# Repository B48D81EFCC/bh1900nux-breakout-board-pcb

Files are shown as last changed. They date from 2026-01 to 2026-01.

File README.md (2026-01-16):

# BH1900NUX Breakout Board PCB
*KiCad project files for a breakout board using the Rohm Semiconductor BH1900NUX temperature sensor.*
## Miniature Temperature Sensor

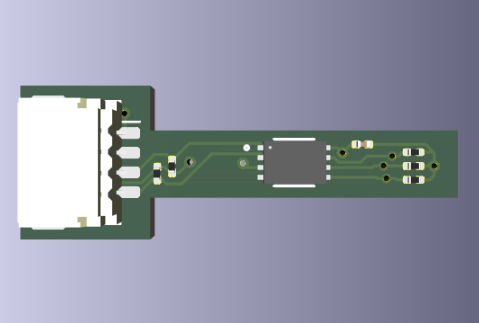
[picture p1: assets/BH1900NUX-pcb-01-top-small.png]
Miniature Temperature Sensor


## Overview
The breakout board simplifies the integration of the **BH1900NUX temperature sensor** into your projects.  
The main goal of this PCB is to have a very compact design that ultimately fits into a stainless steel sleeve with a diameter of around 5mm.

### Features
- **Compact design** of less than 18mm² (0,028 square inch). 
- Connector compatible with many I²C ecosystems
-  **A1 pin** Supported (solder jumper on the back)
- **A2 pin** Supported (solder jumper on the back)
- **A3 pin** Supported (solder jumper on the back)
- **ALERT pin** NOT supported (Pin is not exposed on the PCB)

### JST SH connector pinout

| Pin # | Function |
|---|---|
| 1 | GND |
| 2 | 3.3V |
| 3 | SDA |
| 4 | SCL |

The pinout layout is widely used across different vendors of breakout boards with JST SH connector, allowing to use multiple different sensors on one bus more easily. Although the pin layout is (often) the same, each vendor uses their own brand names (e.g: Qwiic/STEMMA, μŠup, easyC)

> [!CAUTION]
> The design is not 5V compliant and 5V will destroy the sensor.  
> **Use 3.3V only.** 

---
# 3D Render images

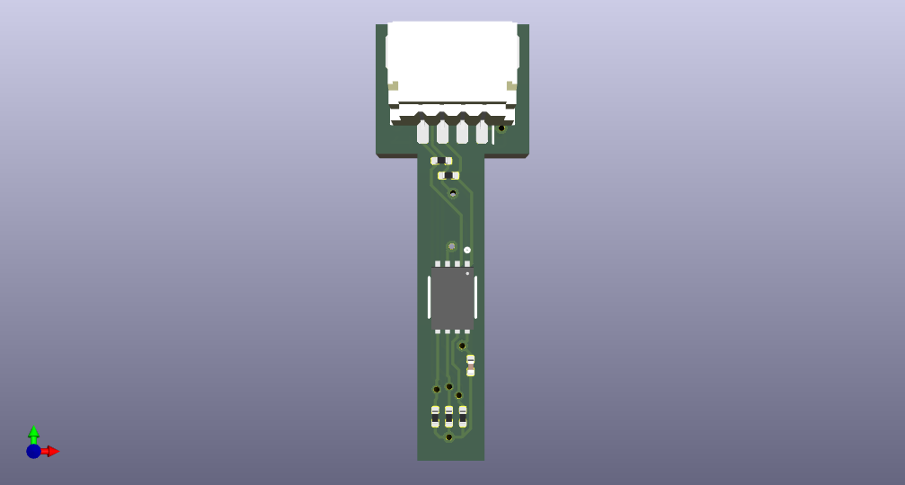
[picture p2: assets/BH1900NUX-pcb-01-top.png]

*Figure: BH1900NUX sensor breakout board top view (Rohm Semiconductor)*

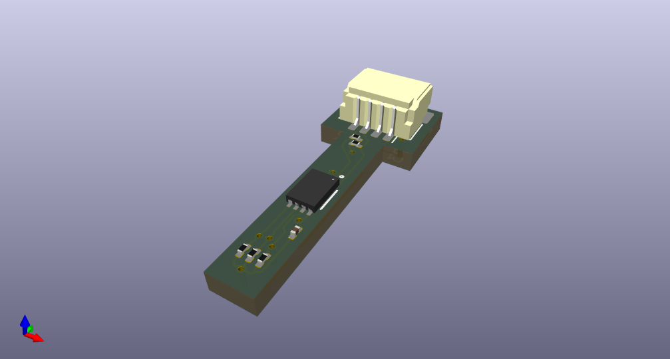
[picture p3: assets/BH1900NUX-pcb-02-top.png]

*Figure: BH1900NUX sensor breakout board top view (Rohm Semiconductor)*

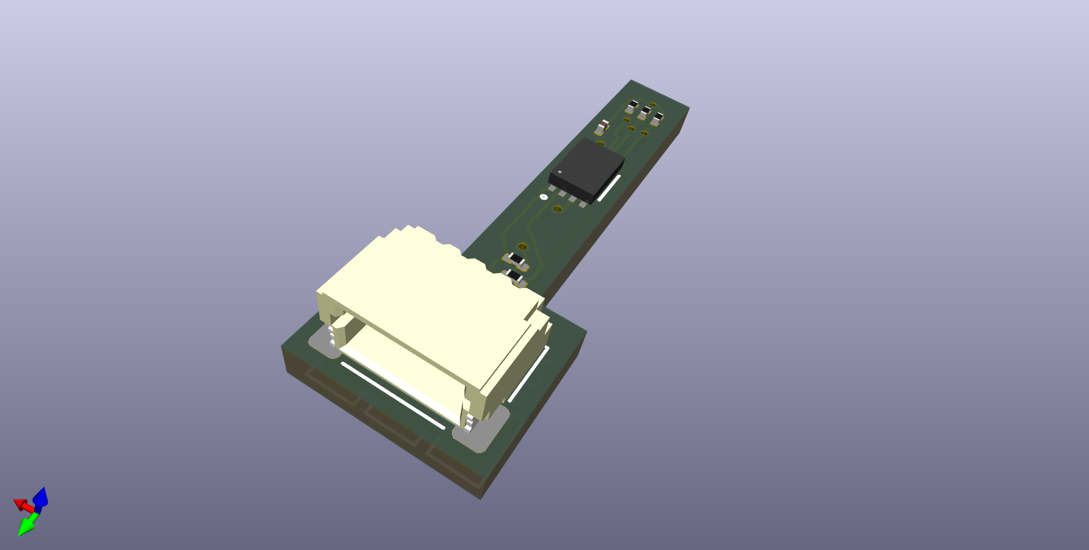
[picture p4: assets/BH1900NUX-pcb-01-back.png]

*Figure: BH1900NUX sensor breakout board back view (Rohm Semiconductor)*

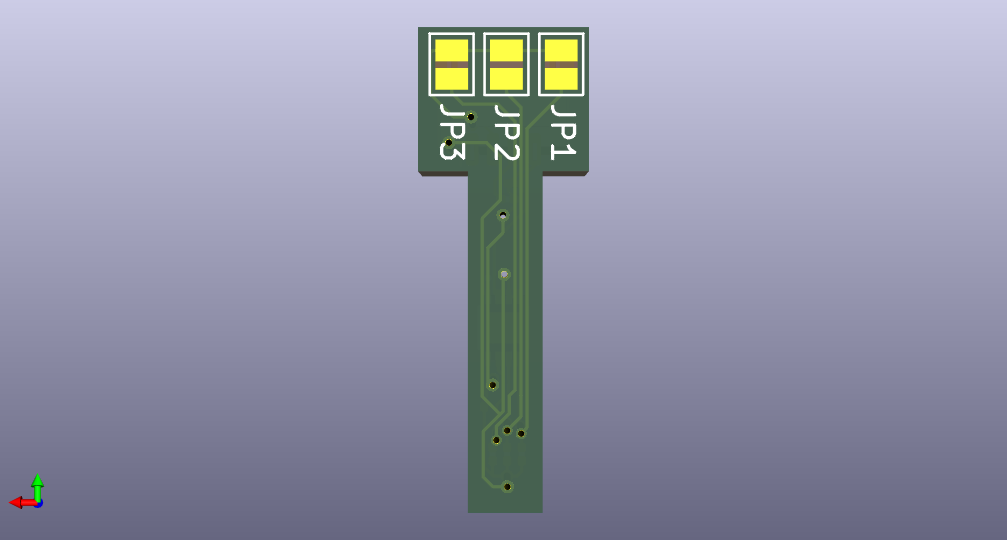
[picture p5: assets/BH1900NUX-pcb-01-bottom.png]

*Figure: BH1900NUX sensor breakout board bottom view (Rohm Semiconductor)*

# Manufacturing
## BOM
| ID / Ref.| Designator | Quantity | Description | Part No. |
|---|---|---|---|---|
| R1,R4,R5 | R_0201_0603Metric | 3 | Resistor, 10k Ohm, SMD | ERJ-1GNF1002C |
| R3,R2 | R_0201_0603Metric | 2 | Resistor, 3.3k Ohm, SMD | ERJ-1GNF3301C |
| J1 | JST_SH_SM04B-SRSS-TB_1x04 | 1 | 01x04 JS SH 1.0mm Horizontal | SM04B-SRSS-TB |
| U1 | VSON008X2030_ROM | 1 | Rohm BH1900NUX-TR IC | BH1900NUX-TR |
| C1 | C_0201_0603Metric | 1 | Capacistor, Ceramic 100nF | GRT033C81E104KE01D |

# Project Supporter
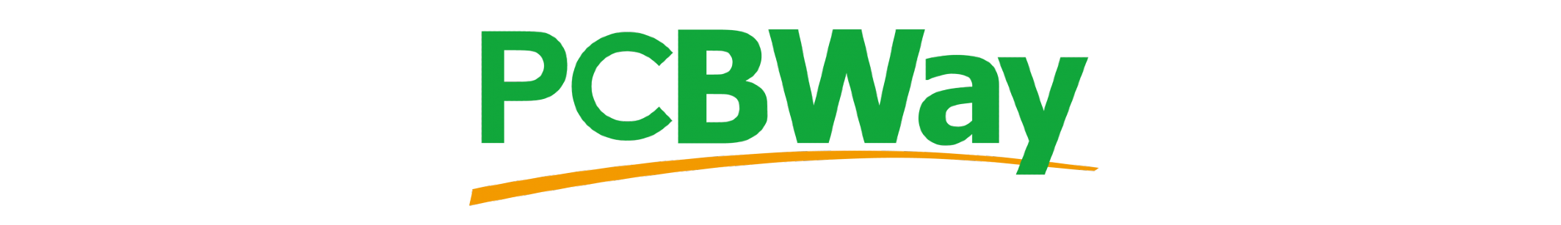
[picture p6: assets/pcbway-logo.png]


[PCBWay](https://www.pcbway.com/) was so kind to help me to realize this project by sponsoring it.
Overall I am very statisfied with the quality of the PCB.  
If you plan to produce and assembly the board I can recommend using PCBWay.
The board looks high-quality, the corners and edges are cleanly cut, and there are no rough breaks, as is often the case with other boards.
There are no visible residues of flux, which is important not only for aesthetic reasons, but also because flux residues can be corrosive.
  
Moreover my service contact during the order process was very patient with me and helped me to fix two issues I had with my design.  
Have a look on you own below:

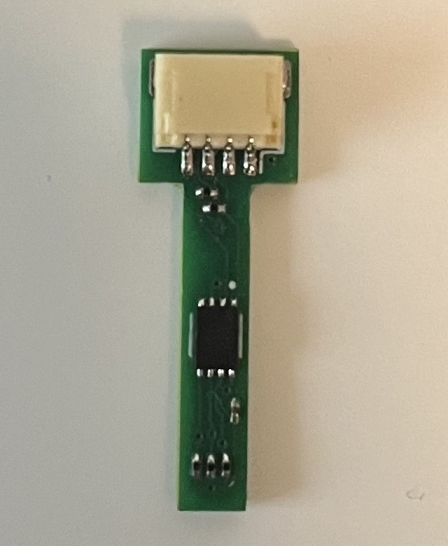
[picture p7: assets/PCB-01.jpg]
   
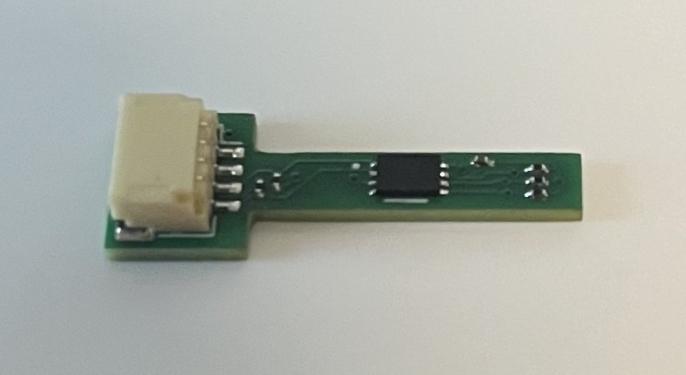
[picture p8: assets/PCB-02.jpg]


# Additional resources
[Official BH1900NUX Product Page (ROHM Website)](https://www.rohm.com/products/sensors-mems/temperature-sensor-ics/bh1900nux-product)  
[PCBWay (Offical Website)](https://www.pcbway.com/)  
[BH1900NUX ESPHome component (ESPHome support)](https://esphome.io/components/sensor/bh1900nux/)

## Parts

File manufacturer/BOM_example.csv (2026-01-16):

Id | Designator | Footprint | Quantity | Designation | Supplier and ref
1 | R1,R4,R5 | R_0201_0603Metric | 3 | 10k | ERJ-1GNF1002C
2 | R3,R2 | R_0201_0603Metric | 2 | 3.3k | ERJ-1GNF3301C
3 | J1 | JST_SH_SM04B-SRSS-TB_1x04-1MP_P1.00mm_Horizontal | 1 | Conn_01x04_Socket | SM04B-SRSS-TB
4 | U1 | VSON008X2030_ROM | 1 | BH1900NUX-TR | BH1900NUX-TR
5 | C1 | C_0201_0603Metric | 1 | 100nF | GRT033C81E104KE01D

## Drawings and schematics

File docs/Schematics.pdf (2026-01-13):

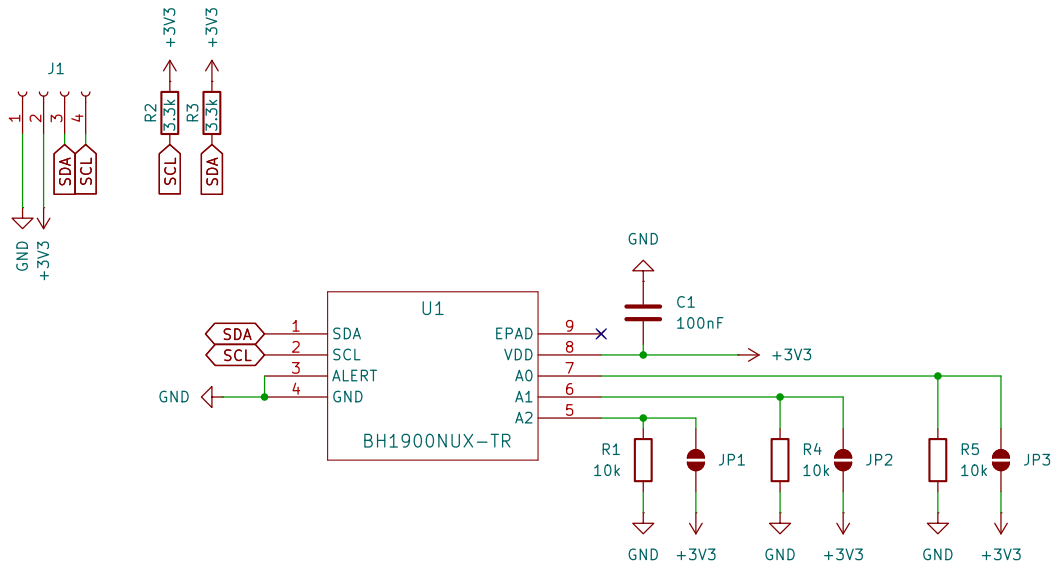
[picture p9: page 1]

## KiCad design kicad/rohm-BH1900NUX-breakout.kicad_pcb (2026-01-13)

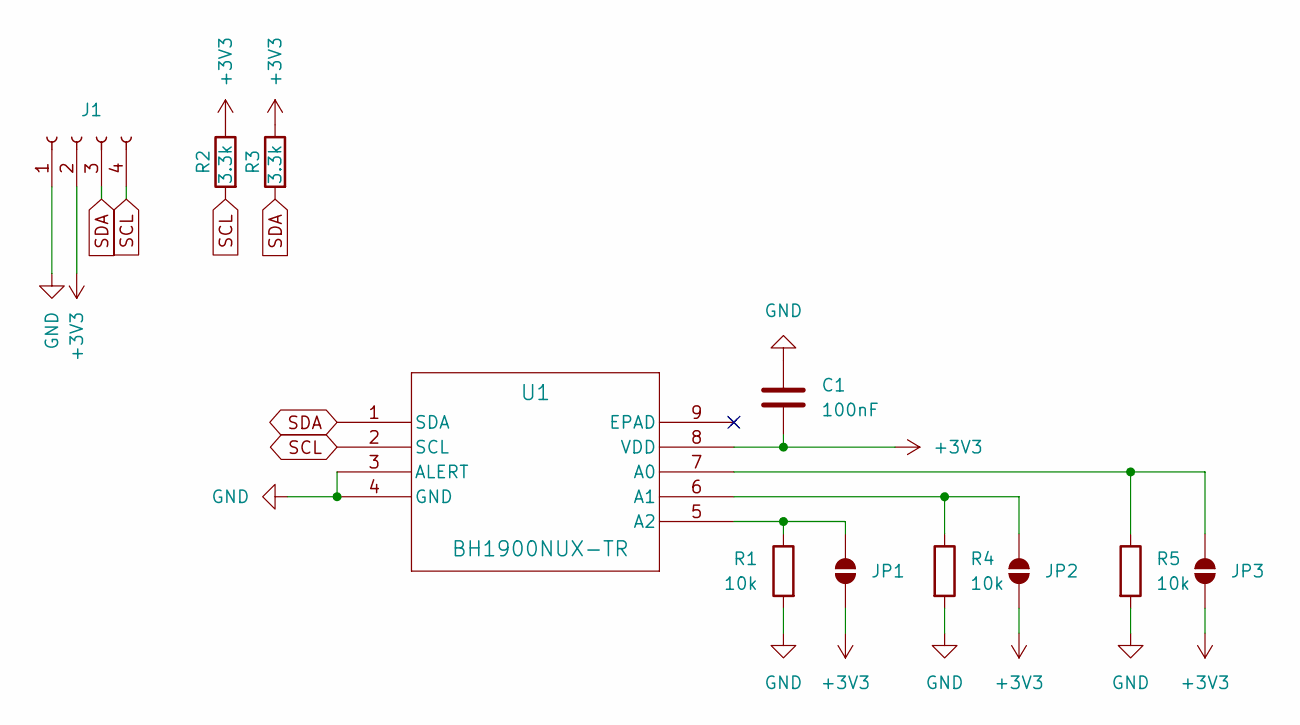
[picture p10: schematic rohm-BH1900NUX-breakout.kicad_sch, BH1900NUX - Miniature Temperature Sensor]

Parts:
C1: 100nF; C_01005_0402Metric
J1: Conn_01x04_Socket; JST_SH_SM04B-SRSS-TB_1x04-1MP_P1.00mm_Horizontal
JP1, JP2, JP3: Jumper_2_Small_Open; SolderJumper-2_P1.3mm_Open_Pad1.0x1.5mm
R1, R4, R5: 10k; R_01005_0402Metric
R2, R3: 3.3k; R_01005_0402Metric
U1: BH1900NUX-TR; VSON008X2030_ROM

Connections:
+3V3: C1.2, J1.2, JP1.2 (B), JP2.1 (A), JP3.1 (A), R2.1, R3.1, U1.8 (VDD)
GND: C1.1, J1.1, R1.2, R4.2, R5.2, U1.3 (ALERT), U1.4 (GND)
unnamed: JP1.1 (A), R1.1, U1.5 (A2)
unnamed: JP2.2 (B), R4.1, U1.6 (A1)
unnamed: JP3.2 (B), R5.1, U1.7 (A0)
SCL: J1.4, R2.2, U1.2 (SCL)
SDA: J1.3, R3.2, U1.1 (SDA)

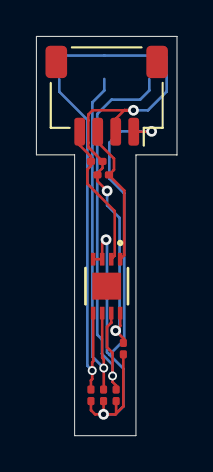
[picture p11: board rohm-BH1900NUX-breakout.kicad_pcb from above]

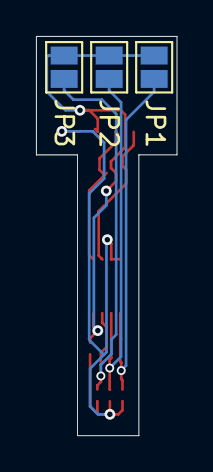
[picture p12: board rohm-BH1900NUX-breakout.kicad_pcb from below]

Board: 2 copper layers, 7.8 x 22.2 mm, 11 parts (3 on the bottom side), 7 nets.

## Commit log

2025-11-20 Layout updated
    [rohm-BH1900NUX-breakout.kicad_pcb, rohm-BH1900NUX-breakout.kicad_sch]
2026-01-13 Final schematics and final layout
    [rohm-BH1900NUX-breakout.kicad_pcb, rohm-BH1900NUX-breakout.kicad_sch]
2026-01-14 Readme updated. BOM file added
    [BOM_example.csv]
2026-01-14 Added some PCB photos
2026-01-16 New project structure
    [BOM_example.csv, rohm-BH1900NUX-breakout.kicad_pcb, rohm-BH1900NUX-breakout.kicad_sch]
